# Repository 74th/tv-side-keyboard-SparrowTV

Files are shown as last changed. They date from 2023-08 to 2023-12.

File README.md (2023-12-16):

# TV Side Keyboard SparrowTV

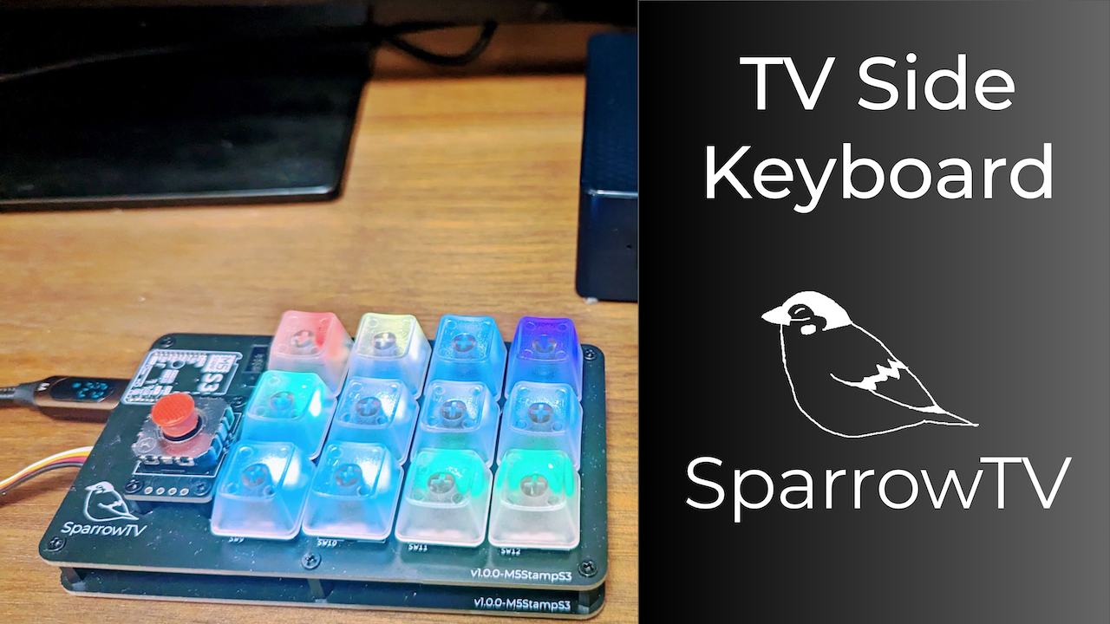
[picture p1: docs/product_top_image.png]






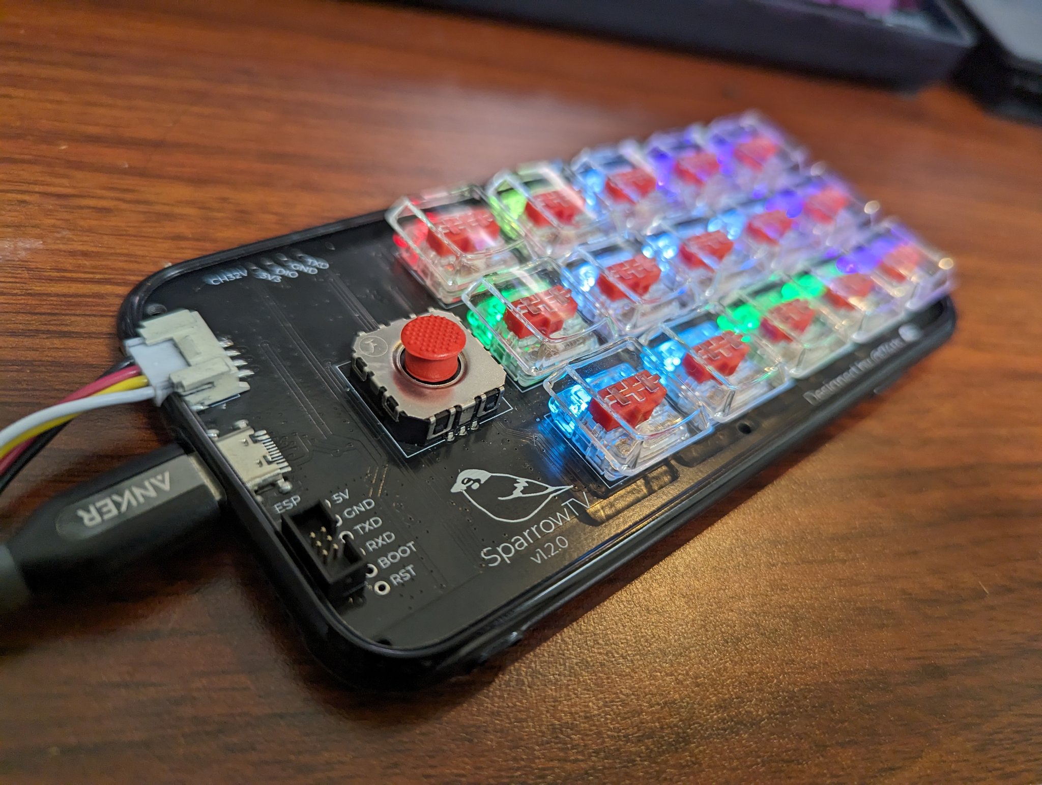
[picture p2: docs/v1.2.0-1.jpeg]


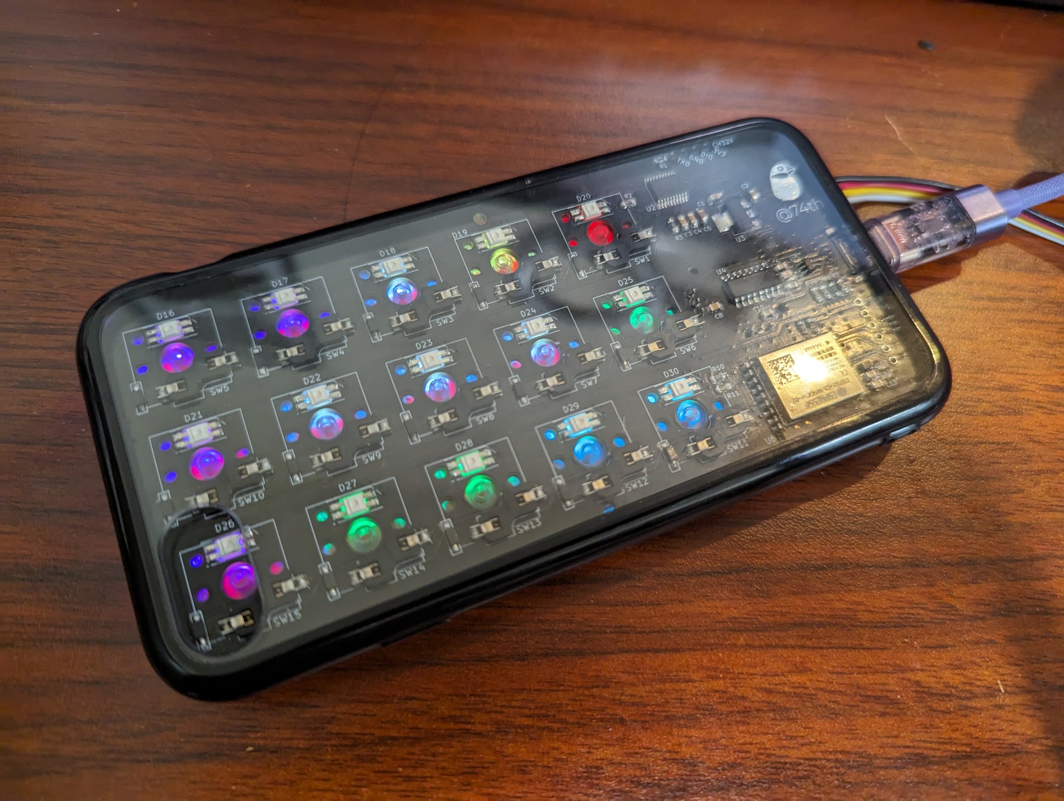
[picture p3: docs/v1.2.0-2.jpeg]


> TV Side Keyboard SparrowTV | ProtoPedia
>
> https://protopedia.net/prototype/4340

> (530) Introduce TV Side Keyboard SparrowTV - YouTube
>
> https://www.youtube.com/watch?v=BaXQt75BodM

この作品は M5Stack Japan Creativity Contest 2023 に応募していました。

ESP32-S3 の USB デバイス機能が使いこなせなかった（USB キーボードでスリープ復帰ができないのを解決できなかった）ので、USB デバイスとして CH9329 を利用し、さらに ESP32-C3 に置き換えました。

## Product versions

### v1.2.0

- ESP32-S3 を ESP32-C3 に置き換え。
- USB キーボードのための IC として CH9329 を利用。
- キーボードマトリックス、ジョイスティックの読み込みに CH32V003F4P6 を利用（v1.0.0 ではジョイスティックのみであった）。

#### Documents

- semantics [pdf](./pcb-kicad/tv-side-keyboard_v1.2.0_semantics.pdf) [kicanvas](https://kicanvas.org/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)
- pcb [kicanvas](https://kicanvas.org/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)

#### BOM

| Reference | Name | Quantity |
| --- | --- | --- |
| C1, C2 | Capacitor 0805 10uF | 2 |
| C3, C4, C6, C8-C10, C12, C13 | Capacitor 0805 100nF | 8 |
| C5, C7, C11 | Capacitor 0805 1uF | 3 |
| CH1 | HY2.0 Socket SMD 4Pin - M5 IR Unit | 1 |
| D1-D15 | Diode SMD 1N4148W | 15 |
| D16-D30 | RGBLED 3528 SK6812MINI-E | 15 |
| J1 | USB Type-C Receptacle | 1 |
| J2 | Box Pin Header 2x3 Pitch 1.27mm | 1 |
| R1 | Register 0805 1Ω | 1 |
| R2 | Register 0805 27Ω | 1 |
| R3, R4, R8, R9 | Register 0805 10kΩ | 4 |
| R5 | Register 0805 42-56kΩ | 1 |
| R6, R7 | Register 0805 5.1kΩ | 2 |
| R10, R11 | Register 0805 1kΩ | 2 |
| SW1-SW15 | Kailh Choc Switch Socket | 15 |
| U1 | Joystick B10K | 1 |
| U2 | MCU TSSOP20 WCH CH32V003F4P6 | 1 |
| U3 | Regulator 3.3V SOT-223 AMS1117-3.3 | 1 |
| U4 | USB Keyboard Mouse Device IC SOIC-16 CH9329 | 1 |
| U5 | USB Power Protection IC SOT-23-6L CH217K | 1 |
| U6 | WiFi MCU Module ESP32-C3-WROOM-02 | 1 |

### v1.0.0

- semantics: [PDF](pcb-kicad/tv-side-keyboard_v1.0.0_semantics.pdf) [kicanvas](https://kicanvas.org/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)
- pcb: [kicanvas](https://kicanvas.org/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)

#### BOM

| Reference | Name | Quantity |
| --- | --- | --- |
| CH1 | HY2.0 Socket SMD 4Pin - JoyPoint | 1 |
| CH2 | HY2.0 Socket SMD 4Pin - M5 IR Unit | 1 |
| D1-D12 | Diode SMD 1N4148W | 12 |
| D13-D24 | RGBLED 3528 SK6812MINI-E | 12 |
| J1 | Box Pin Header 2x3 Pitch 1.27mm | 1 |
| R1 | Capacitor 0805 27F | 1 |
| R2, R3 | Capacitor 0805 10kF | 2 |
| SW1-SW12  | Kailh Choc Switch Socket | 12 |
| U1 | MCU Module M5Stamp S3 | 1 |

## License

MIT

日本では販売しないでいただけると助かります。

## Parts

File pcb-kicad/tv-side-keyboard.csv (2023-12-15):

Reference | Value | Footprint | Sim.Device | Sim.Pins | 数量
C1, C2 | 10u | $74th:Capacitor_0805_2012 |  |  | 2
C3, C4, C6, C8-C10, C12, C13 | 100n | $74th:Capacitor_0805_2012 |  |  | 8
C5, C7, C11 | 1u | $74th:Capacitor_0805_2012 |  |  | 3
CH1 | M5 IR Unit | $74th:HY2.0_Socket_SMD_4Pin |  |  | 1
CH2 | SWD 1Wire & UART TX | 74th:PinOut_4Pin |  |  | 1
D1-D15 | 1N4148W | $sparrow62:D3_SMD_v2 | D | 1=K 2=A | 15
D16-D30 | SK6812MINI | $74th:YS-SK6812MINI-E-BACK-RIGHT |  |  | 15
J1 | Keyboard USB | $74th:USB-C-12-Pin-MidMount-ali-v5 |  |  | 1
J2 | ESPProg-Port | $74th:BoxPinHeader_2x03_P1.27mm_Vertical |  |  | 1
J3 | ESPProg-Port | $74th:6Pin |  |  | 1
R1 | 1 | $74th:Register_0805_2012 |  |  | 1
R2 | 27 | $74th:Register_0805_2012 |  |  | 1
R3, R4, R8, R9 | 10k | $74th:Register_0805_2012 |  |  | 4
R5 | 42k | $74th:Register_0805_2012 |  |  | 1
R6, R7 | 5.1k | $74th:Register_0805_2012 |  |  | 2
R10, R11 | 1k | $74th:Register_0805_2012 |  |  | 2
SW1-SW15 | SW_Push | $sparrow62:Choc_1Side_1.0u |  |  | 15
U1 | joystick-b10k | $74th:JOYSTICK-B10K |  |  | 1
U2 | CH32V003F4P6 | Package_SO:TSSOP-20_4.4x6.5mm_P0.65mm |  |  | 1
U3 | Regulator_AMS117-3.3 | Package_TO_SOT_SMD:SOT-223-3_TabPin2 |  |  | 1
U4 | CH9329 | Package_SO:SOIC-16_3.9x9.9mm_P1.27mm |  |  | 1
U5 | CH217K | Package_TO_SOT_SMD:SOT-23-6 |  |  | 1
U6 | ESP32-C3-WROOM-02 | $74th-imported:ESP32-C3-WROOM-02 |  |  | 1

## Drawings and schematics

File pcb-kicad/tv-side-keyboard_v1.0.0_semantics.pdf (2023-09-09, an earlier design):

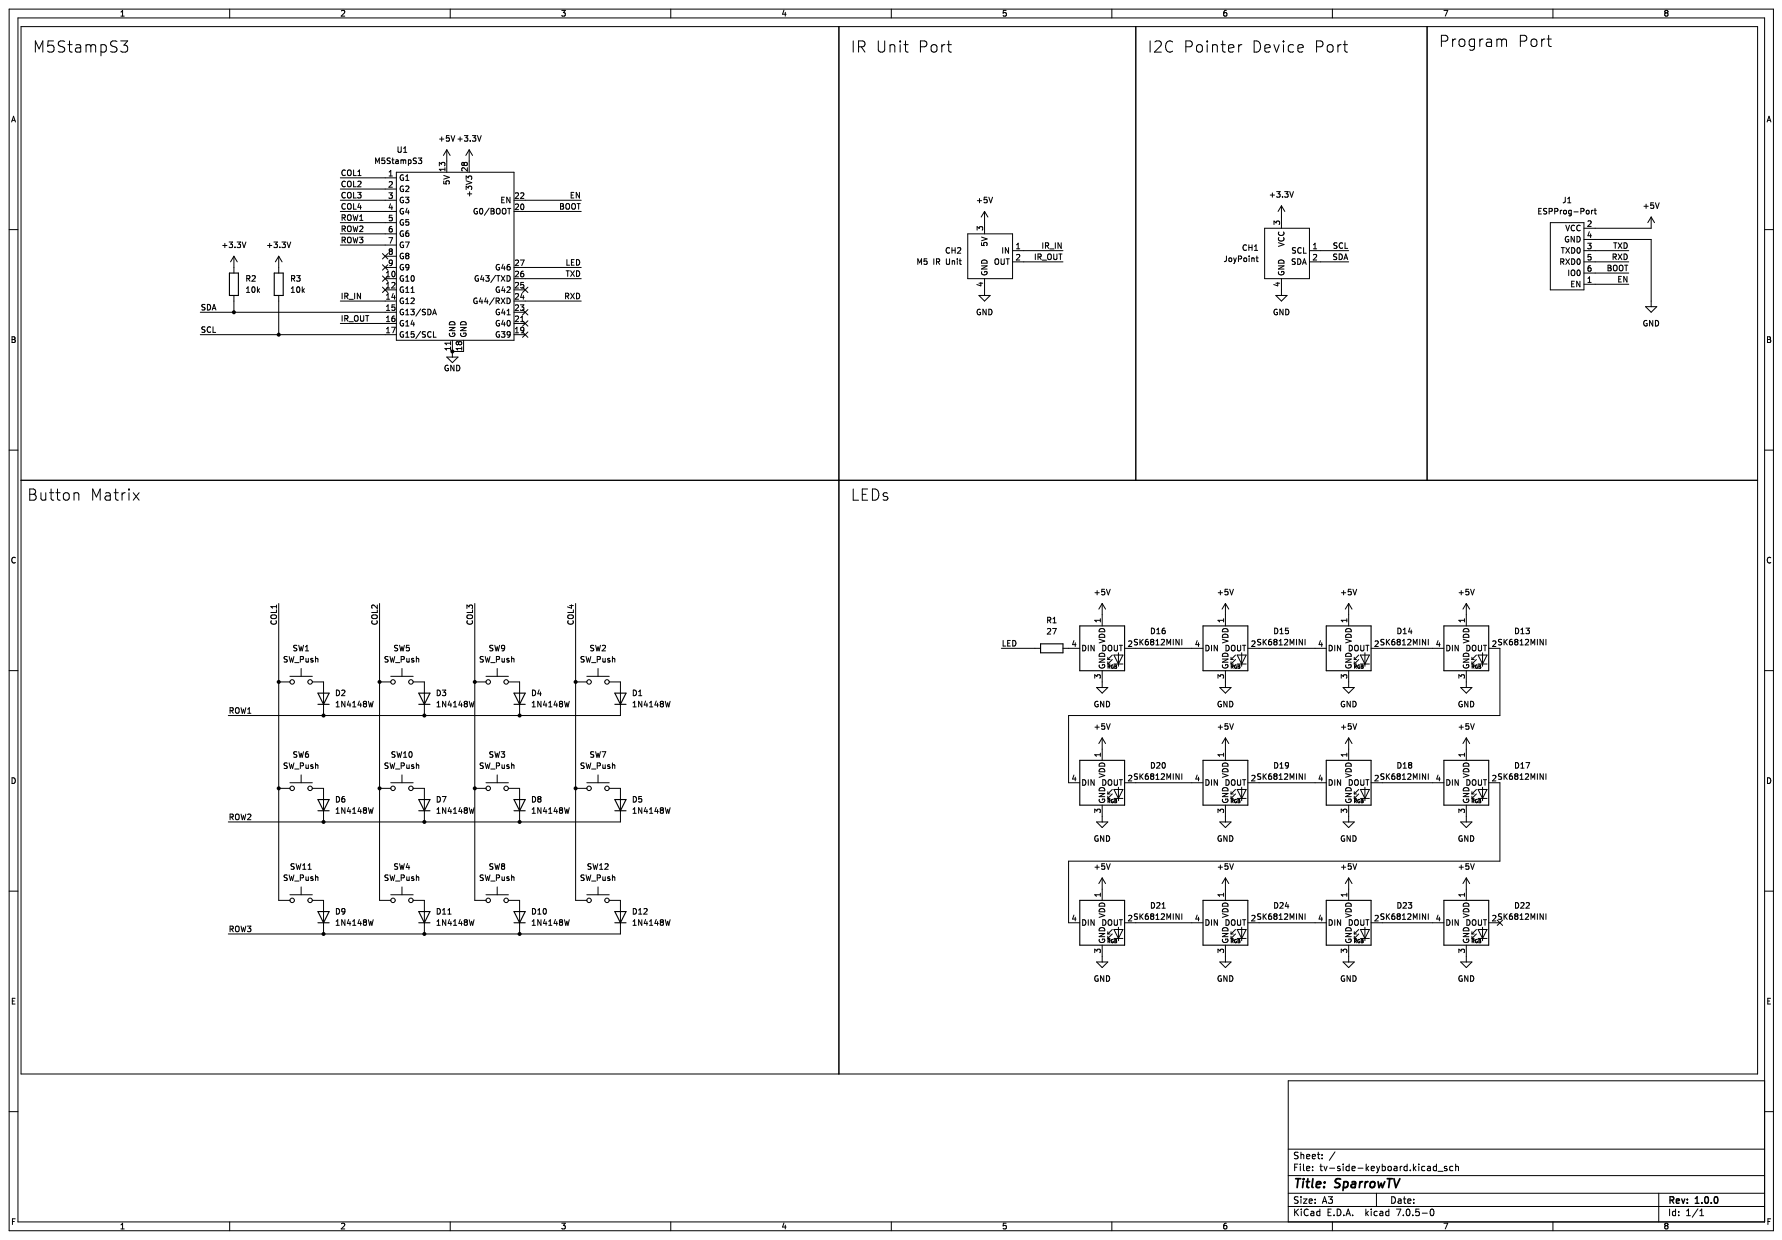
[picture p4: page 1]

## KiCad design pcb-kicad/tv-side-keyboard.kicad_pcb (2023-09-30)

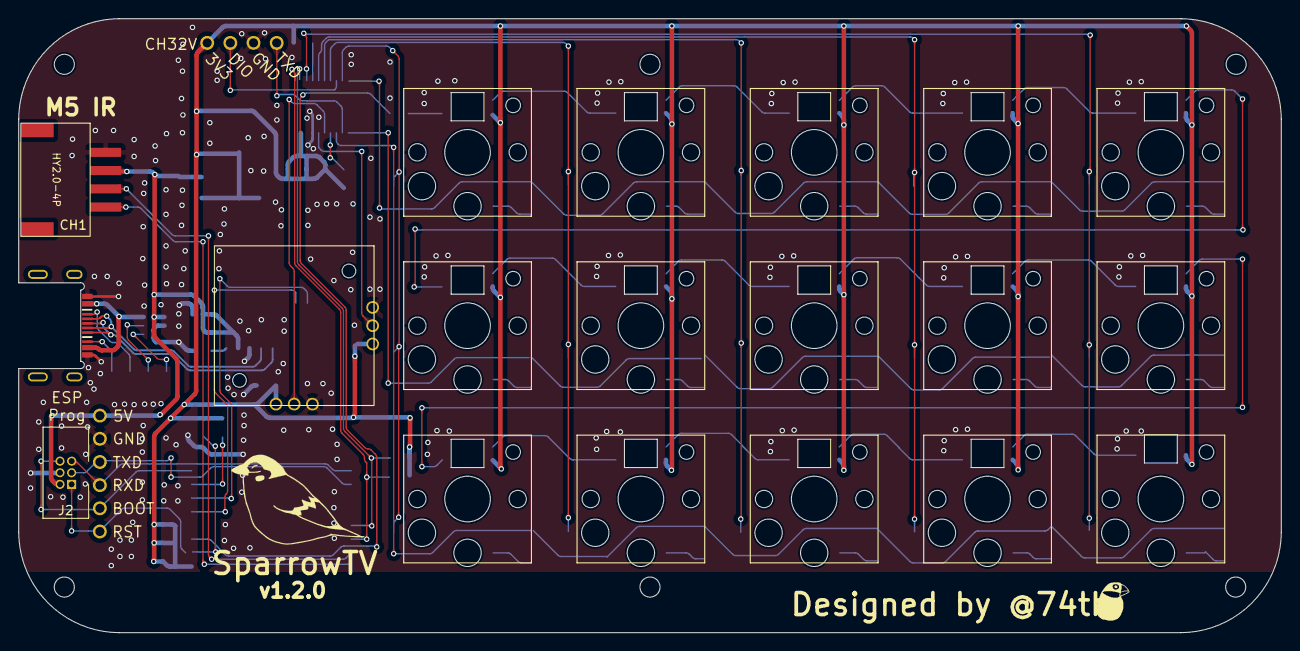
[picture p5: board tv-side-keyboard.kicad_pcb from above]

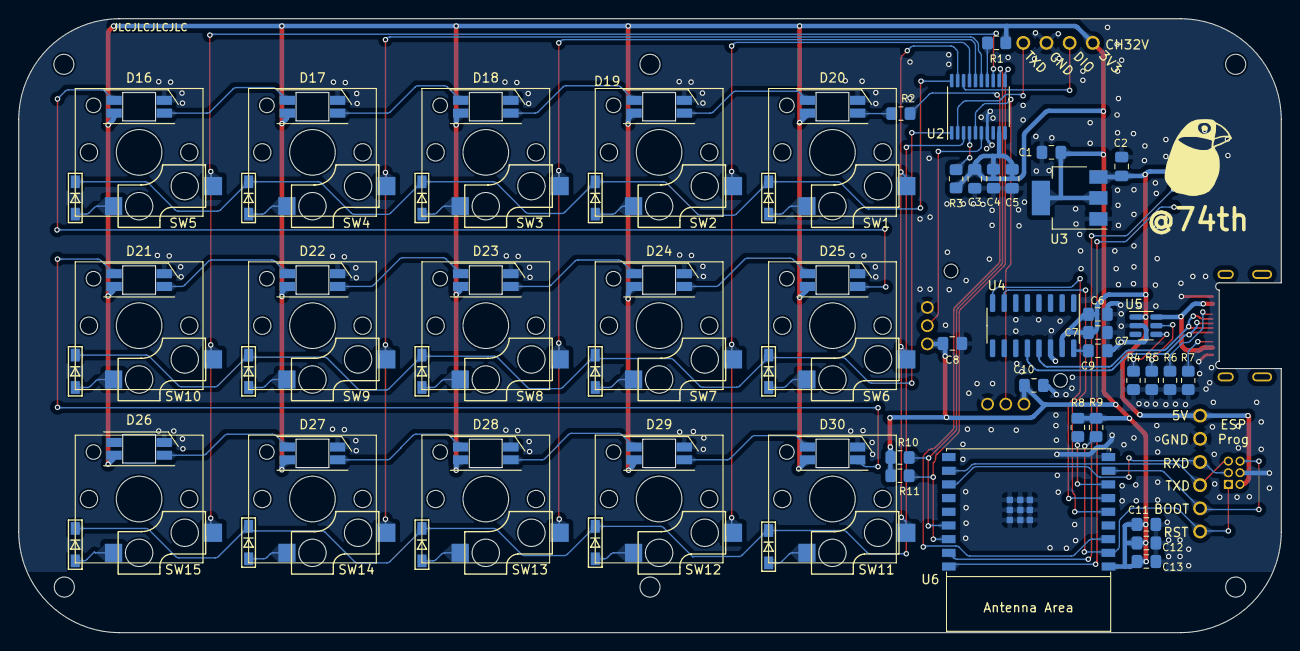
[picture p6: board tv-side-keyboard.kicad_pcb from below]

Board: 2 copper layers, 138.4 x 67.3 mm, 87 parts (46 on the bottom side), 67 nets.

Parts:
C1, C2: 10u; Capacitor_0805_2012
C3, C4, C6, C8, C9, C10, C12, C13: 100n; Capacitor_0805_2012
C5, C7, C11: 1u; Capacitor_0805_2012
CH1: M5 IR Unit; HY2.0_Socket_SMD_4Pin
CH2: SWD 1Wire & UART TX; PinOut_4Pin
D1, D2, D3, D4, D5, D6, D7, D8, D9, D10, D11, D12, D13, D14, D15: 1N4148W; D3_SMD_v2
D16, D17, D18, D19, D20, D21, D22, D23, D24, D25, D26, D27, D28, D29, D30: SK6812MINI; YS-SK6812MINI-E-BACK-RIGHT
J1: Keyboard USB; USB-C-12-Pin-MidMount-ali-v5
J2: ESPProg-Port; BoxPinHeader_2x03_P1.27mm_Vertical
J3: ESPProg-Port; 6Pin
M1, M2, M3, M4, M5, M6: M2-Hole
MISC-ICON: LOGO; Logo_74th_5mm
R1: 1; Register_0805_2012
R2: 27; Register_0805_2012
R3, R4, R8, R9: 10k; Register_0805_2012
R5: 42k; Register_0805_2012
R6, R7: 5.1k; Register_0805_2012
R10, R11: 1k; Register_0805_2012
SW1, SW2, SW3, SW4, SW5, SW6, SW7, SW8, SW9, SW10, SW11, SW12, SW13, SW14, SW15: SW_Push; Choc_1Side_1.0u
U1: joystick-b10k; JOYSTICK-B10K
U2: CH32V003F4P6; TSSOP-20_4.4x6.5mm_P0.65mm
U3: Regulator_AMS117-3.3; SOT-223-3_TabPin2
U4: CH9329; SOIC-16_3.9x9.9mm_P1.27mm
U5: CH217K; SOT-23-6
U6: ESP32-C3-WROOM-02

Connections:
+3.3V: C1.1, C3.1, C4.1, C5.1, C8.1, C10.1, C11.1, C12.1, C13.1, CH2.1 (VCC), D16.1 (VDD), D17.1 (VDD), D18.1 (VDD), D19.1 (VDD), D20.1 (VDD), D21.1 (VDD), D22.1 (VDD), D23.1 (VDD), D24.1 (VDD), D25.1 (VDD), D26.1 (VDD), D27.1 (VDD), D28.1 (VDD), D29.1 (VDD), D30.1 (VDD), R1.1, R3.1, R8.1, R9.1, R10.1, R11.1, U1.1 (XIN1), U1.4 (YIN1), U2.9 (VDD), U3.2 (VO), U6.1 (3V3)
+5V: C2.1, C6.1, C7.1, CH1.3 (5V), J2.2 (VCC), J3.1 (VCC), U3.3 (VI), U4.15 (VCC), U5.1 (VOUT)
/CH32V003_SWDIO: CH2.2 (SWDIO), U2.18 (SWIO/PD1)
/CH32V003_TXD: CH2.4 (TXD), U2.2 (PD5/UART_TX/ADC5)
/CH9329_DM: J1.2 (D-), U4.13 (UD-)
/CH9329_DP: J1.3 (D+), U4.12 (UD+)
/CH9329_RXD: U4.8 (RXD), U6.6 (GPIO7)
/CH9329_TXD: U4.7 (TXD), U6.5 (GPIO6)
/COL1: SW1.1, SW6.1, SW11.1, U2.19 (PD2/ADC3)
/COL2: SW2.1, SW7.1, SW12.1, U2.17 (PC7/SPI_MISO)
/COL3: SW3.1, SW8.1, SW13.1, U2.16 (PC6/SPI_MOSI)
/COL4: SW4.1, SW9.1, SW14.1, U2.15 (PC5/SPI_SCK)
/COL5: SW5.1, SW10.1, SW15.1, U2.13 (PC3)
/ESP32C3_BOOT: J2.6 (IO0), J3.5 (IO0), U6.8 (GPIO9)
/ESP32C3_RST: J2.1 (EN), J3.6 (EN), R9.2, U6.2 (EN/CHIP_PU)
/ESP32C3_RXD: J2.5 (RXD0), J3.4 (RXD0), U6.11 (GPIO20/U0RXD)
/ESP32C3_TXD: J2.3 (TXD0), J3.3 (TXD0), U6.12 (GPIO21/U0TXD)
/IR_IN: CH1.1 (IN), U6.18 (GPIO0/ADC1_CH0/XTAL_32K_P)
/IR_OUT: CH1.2 (OUT), U6.17 (GPIO1/ADC1_CH1/XTAL_32K_N)
/LED: R2.2, U6.3 (GPIO4/ADC1_CH4)
/ROW1: D1.1 (K), D2.1 (K), D3.1 (K), D4.1 (K), D5.1 (K), U2.20 (PD3/UART_CTS/ADC4)
/ROW2: D6.1 (K), D7.1 (K), D8.1 (K), D9.1 (K), D10.1 (K), U2.1 (PD4/UART_CK/ADC7)
/ROW3: D11.1 (K), D12.1 (K), D13.1 (K), D14.1 (K), D15.1 (K), U2.3 (PD6/UART_RX/ADC6)
/SCL: R10.2, U2.12 (PC2/I2C_SCL/UART_RTS), U6.15 (GPIO3/ADC1_CH3)
/SDA: R11.2, U2.11 (PC1/I2C_SDA/SPI_NSS), U6.16 (GPIO2/ADC1_CH2)
/XOUT: U1.2 (XOUT), U2.6 (PA2/ADC0/OSC_OUT)
/YOUT: U1.5 (YOUT), U2.5 (PA1/ADC1/OSC_IN)
GND: C1.2, C2.2, C3.2, C4.2, C5.2, C6.2, C7.2, C8.2, C9.2, C10.2, C11.2, C12.2, C13.2, CH1.4 (GND), CH2.3 (GND), D16.3 (GND), D17.3 (GND), D18.3 (GND), D19.3 (GND), D20.3 (GND), D21.3 (GND), D22.3 (GND), D23.3 (GND), D24.3 (GND), D25.3 (GND), D26.3 (GND), D27.3 (GND), D28.3 (GND), D29.3 (GND), D30.3 (GND), J1.4 (GND), J2.4 (GND), J3.2 (GND), R4.2, R5.2, R6.2, R7.2, U1.3 (XIN2), U1.6 (YIN2), U2.7 (VSS), U3.1 (GND), U4.14 (GND), U5.2 (GND), U6.9 (GND), U6.19 (GND)
unnamed: D1.2 (A), SW1.2
unnamed: D2.2 (A), SW2.2
unnamed: D3.2 (A), SW3.2
unnamed: D4.2 (A), SW4.2
unnamed: D5.2 (A), SW5.2
unnamed: D6.2 (A), SW6.2
unnamed: D7.2 (A), SW7.2
unnamed: D8.2 (A), SW8.2
unnamed: D9.2 (A), SW9.2
unnamed: D10.2 (A), SW10.2
unnamed: D11.2 (A), SW12.2
unnamed: D12.2 (A), SW14.2
unnamed: D13.2 (A), SW13.2
unnamed: D14.2 (A), SW15.2
unnamed: D15.2 (A), SW11.2
unnamed: D16.4 (DIN), D17.2 (DOUT)
unnamed: D16.2 (DOUT), D25.4 (DIN)
unnamed: D17.4 (DIN), D18.2 (DOUT)
unnamed: D18.4 (DIN), D19.2 (DOUT)
unnamed: D19.4 (DIN), D20.2 (DOUT)
unnamed: D20.4 (DIN), R2.1
unnamed: D21.4 (DIN), D22.2 (DOUT)
unnamed: D21.2 (DOUT), D30.4 (DIN)
unnamed: D22.4 (DIN), D23.2 (DOUT)
unnamed: D23.4 (DIN), D24.2 (DOUT)
unnamed: D24.4 (DIN), D25.2 (DOUT)
unnamed: D26.4 (DIN), D27.2 (DOUT)
unnamed: D27.4 (DIN), D28.2 (DOUT)
unnamed: D28.4 (DIN), D29.2 (DOUT)
unnamed: D29.4 (DIN), D30.2 (DOUT)
unnamed: J1.5 (CC1), R6.1
unnamed: J1.6 (CC2), R7.1
unnamed: R1.2, U2.14 (PC4/ADC2)
unnamed: R3.2, U2.4 (PD7/NRST)
unnamed: C9.1, U4.16 (V33)
unnamed: R4.1, U5.4 (EN#)
unnamed: R5.1, U5.5 (ISET)
unnamed: R8.2, U6.7 (GPIO8)
VBUS: J1.1 (VBUS), U5.6 (VIN)

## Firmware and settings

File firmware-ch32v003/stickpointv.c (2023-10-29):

#include "ch32v003fun.h"
#include "stickpointv.h"
#include "ch32v003_GPIO_branchless.h"
#include <stdio.h>

#define I2C_SLAVE_ADDRESS 0xA

#define ADC_NUMCHLS 3
#define I2C_BUF_SIZE 8
#define ROW1_PIN GPIOv_from_PORT_PIN(GPIO_port_D, 3)
#define ROW2_PIN GPIOv_from_PORT_PIN(GPIO_port_D, 4)
#define ROW3_PIN GPIOv_from_PORT_PIN(GPIO_port_D, 6)
#define COL1_PIN GPIOv_from_PORT_PIN(GPIO_port_D, 2)
#define COL2_PIN GPIOv_from_PORT_PIN(GPIO_port_C, 7)
#define COL3_PIN GPIOv_from_PORT_PIN(GPIO_port_C, 6)
#define COL4_PIN GPIOv_from_PORT_PIN(GPIO_port_C, 5)
#define COL5_PIN GPIOv_from_PORT_PIN(GPIO_port_C, 3)

volatile uint8_t i2c_buf[I2C_BUF_SIZE];
volatile uint16_t adc_buf[ADC_NUMCHLS];

void I2C1_EV_IRQHandler(void) __attribute__((interrupt));
void I2C1_ER_IRQHandler(void) __attribute__((interrupt));

void init_rcc(void)
{
    RCC->CFGR0 &= ~(0x1F << 11);

    RCC->APB2PCENR |= RCC_APB2Periph_GPIOA | RCC_APB2Periph_GPIOC | RCC_APB2Periph_GPIOD | RCC_APB2Periph_ADC1;
    RCC->APB1PCENR |= RCC_APB1Periph_I2C1;
}

void init_i2c_slave(uint8_t address)
{
    // https://github.com/cnlohr/ch32v003fun/blob/master/examples/i2c_slave/i2c_slave.h

    // PC1 is SDA, 10MHz Output, alt func, open-drain
    GPIOC->CFGLR &= ~(0xf << (4 * 1));
    GPIOC->CFGLR |= (GPIO_Speed_10MHz | GPIO_CNF_OUT_OD_AF) << (4 * 1);

    // PC2 is SCL, 10MHz Output, alt func, open-drain
    GPIOC->CFGLR &= ~(0xf << (4 * 2));
    GPIOC->CFGLR |= (GPIO_Speed_10MHz | GPIO_CNF_OUT_OD_AF) << (4 * 2);

    // Reset I2C1 to init all regs
    RCC->APB1PRSTR |= RCC_APB1Periph_I2C1;
    RCC->APB1PRSTR &= ~RCC_APB1Periph_I2C1;

    I2C1->CTLR1 |= I2C_CTLR1_SWRST;
    I2C1->CTLR1 &= ~I2C_CTLR1_SWRST;

    // Set module clock frequency
    uint32_t prerate = 2000000; // I2C Logic clock rate, must be higher than the bus clock rate
    I2C1->CTLR2 |= (APB_CLOCK / prerate) & I2C_CTLR2_FREQ;

    // Enable interrupts
    I2C1->CTLR2 |= I2C_CTLR2_ITBUFEN;
    I2C1->CTLR2 |= I2C_CTLR2_ITEVTEN; // Event interrupt
    I2C1->CTLR2 |= I2C_CTLR2_ITERREN; // Error interrupt

    NVIC_EnableIRQ(I2C1_EV_IRQn); // Event interrupt
    NVIC_SetPriority(I2C1_EV_IRQn, 2 << 4);
    NVIC_EnableIRQ(I2C1_ER_IRQn); // Error interrupt
    // Set clock configuration
    uint32_t clockrate = 1000000;                                                    // I2C Bus clock rate, must be lower than the logic clock rate
    I2C1->CKCFGR = ((APB_CLOCK / (3 * clockrate)) & I2C_CKCFGR_CCR) | I2C_CKCFGR_FS; // Fast mode 33% duty cycle
    // I2C1->CKCFGR = ((APB_CLOCK/(25*clockrate))&I2C_CKCFGR_CCR) | I2C_CKCFGR_DUTY | I2C_CKCFGR_FS; // Fast mode 36% duty cycle
    // I2C1->CKCFGR = (APB_CLOCK/(2*clockrate))&I2C_CKCFGR_CCR; // Standard mode good to 100kHz

    // Set I2C address
    I2C1->OADDR1 = address << 1;

    // Enable I2C
    I2C1->CTLR1 |= I2C_CTLR1_PE;

    // Acknowledge the first address match event when it happens
    I2C1->CTLR1 |= I2C_CTLR1_ACK;
}

void init_adc(void)
{
    // https://github.com/cnlohr/ch32v003fun/tree/master/examples/adc_dma_opamp

    // ADCCLK = 24 MHz => RCC_ADCPRE = 0: divide by 2
    RCC->CFGR0 &= ~(0x1F << 11);

    // A0 PA2
    GPIOA->CFGLR &= ~(0xf << (4 * 2)); // CNF = 00: Analog, MODE = 00: Input

    // A1 PA1
    GPIOA->CFGLR &= ~(0xf << (4 * 2)); // CNF = 00: Analog, MODE = 00: Input

    // A2 PA4
    GPIOC->CFGLR &= ~(0xf << (4 * 4)); // CNF = 00: Analog, MODE = 00: Input

    // Reset the ADC to init all regs
    RCC->APB2PRSTR |= RCC_APB2Periph_ADC1;
    RCC->APB2PRSTR &= ~RCC_APB2Periph_ADC1;

    // Set up four conversions on chl 0, 1, 2
    ADC1->RSQR1 = (ADC_NUMCHLS - 1) << 20; // four chls in the sequence
    ADC1->RSQR2 = 0;
    ADC1->RSQR3 = (0 << (5 * 0)) | (1 << (5 * 1)) | (2 << (5 * 2));

    // set sampling time for chl 7, 4, 3, 2
    // 0:7 => 3/9/15/30/43/57/73/241 cycles
    ADC1->SAMPTR2 = (7 << (3 * 0)) | (7 << (3 * 1)) | (7 << (3 * 2));

    // turn on ADC
    ADC1->CTLR2 |= ADC_ADON;

    // Reset calibration
    ADC1->CTLR2 |= ADC_RSTCAL;
    while (ADC1->CTLR2 & ADC_RSTCAL)
        ;

    // Calibrate
    ADC1->CTLR2 |= ADC_CAL;
    while (ADC1->CTLR2 & ADC_CAL)
        ;

    // Turn on DMA
    RCC->AHBPCENR |= RCC_AHBPeriph_DMA1;

    // DMA1_Channel1 is for ADC
    DMA1_Channel1->PADDR = (uint32_t)&ADC1->RDATAR;
    DMA1_Channel1->MADDR = (uint32_t)adc_buf;
    DMA1_Channel1->CNTR = ADC_NUMCHLS;
    DMA1_Channel1->CFGR =
        DMA_M2M_Disable |
        DMA_Priority_VeryHigh |
        DMA_MemoryDataSize_HalfWord |
        DMA_PeripheralDataSize_HalfWord |
        DMA_MemoryInc_Enable |
        DMA_Mode_Circular |
        DMA_DIR_PeripheralSRC;

    // Turn on DMA channel 1
    DMA1_Channel1->CFGR |= DMA_CFGR1_EN;

    // enable scanning
    ADC1->CTLR1 |= ADC_SCAN;

    // Enable continuous conversion and DMA
    ADC1->CTLR2 |= ADC_CONT | ADC_DMA | ADC_EXTSEL;

    // start conversion
    ADC1->CTLR2 |= ADC_SWSTART;
}

void init_gpio(void)
{
    GPIO_port_enable(GPIO_port_C);
    GPIO_port_enable(GPIO_port_D);
    GPIO_pinMode(ROW1_PIN, GPIO_pinMode_I_pullDown, GPIO_Speed_10MHz);
    GPIO_pinMode(ROW2_PIN, GPIO_pinMode_I_pullDown, GPIO_Speed_10MHz);
    GPIO_pinMode(ROW3_PIN, GPIO_pinMode_I_pullDown, GPIO_Speed_10MHz);
    GPIO_pinMode(COL1_PIN, GPIO_pinMode_O_pushPull, GPIO_Speed_10MHz);
    GPIO_pinMode(COL2_PIN, GPIO_pinMode_O_pushPull, GPIO_Speed_10MHz);
    GPIO_pinMode(COL3_PIN, GPIO_pinMode_O_pushPull, GPIO_Speed_10MHz);
    GPIO_pinMode(COL4_PIN, GPIO_pinMode_O_pushPull, GPIO_Speed_10MHz);
    GPIO_pinMode(COL5_PIN, GPIO_pinMode_O_pushPull, GPIO_Speed_10MHz);
}

uint8_t i2c_scan_position = 0;

void I2C1_EV_IRQHandler(void)
{
    uint16_t STAR1, STAR2 __attribute__((unused));
    STAR1 = I2C1->STAR1;
    STAR2 = I2C1->STAR2;

#ifdef FUNCONF_USE_UARTPRINTF
    printf("EV STAR1: 0x%04x STAR2: 0x%04x\r\n", STAR1, STAR2);
#endif

    I2C1->CTLR1 |= I2C_CTLR1_ACK;

    if (STAR1 & I2C_STAR1_ADDR) // 0x0002
    {
#ifdef FUNCONF_USE_UARTPRINTF
        printf("ADDR\r\n");
#endif
        // 最初のイベント
        // read でも write でも必ず最初に呼ばれる
        i2c_scan_position = 0;
    }

    if (STAR1 & I2C_STAR1_RXNE) // 0x0040
    {
#ifdef FUNCONF_USE_UARTPRINTF
        printf("RXNE write event: pos:%d\r\n", i2c_scan_position);
#endif
        // 1byte 受信
        I2C1->DATAR;
    }

    if (STAR1 & I2C_STAR1_TXE) // 0x0080
    {
        // 1byte の read イベント（slave -> master）
#ifdef FUNCONF_USE_UARTPRINTF
        printf("TXE write event: pos:%d\r\n", i2c_scan_position);
#endif
        if (i2c_scan_position < I2C_BUF_SIZE)
        {
            // 1byte 送信
            uint8_t data = i2c_buf[i2c_scan_position];
            I2C1->DATAR = data;
            i2c_scan_position++;
        }
        else
        {
            // 1byte 送信
            I2C1->DATAR = 0x00;
        }
    }
}

void I2C1_ER_IRQHandler(void)
{
    uint16_t STAR1 = I2C1->STAR1;

#ifdef FUNCONF_USE_UARTPRINTF
    printf("ER STAR1: 0x%04x\r\n", STAR1);
#endif

    if (STAR1 & I2C_STAR1_BERR)           // 0x0100
    {                                     // Bus error
        I2C1->STAR1 &= ~(I2C_STAR1_BERR); // Clear error
    }

    if (STAR1 & I2C_STAR1_ARLO)           // 0x0200
    {                                     // Arbitration lost error
        I2C1->STAR1 &= ~(I2C_STAR1_ARLO); // Clear error
    }

    if (STAR1 & I2C_STAR1_AF)           // 0x0400
    {                                   // Acknowledge failure
        I2C1->STAR1 &= ~(I2C_STAR1_AF); // Clear error
    }
}

// const int max = 1024;
const int32_t deadzone = 100;
const int32_t high_zone = 7;
const int32_t middle = 200;
const uint32_t loop_ms = 12;
const uint32_t max_ms = 4028;

int32_t last_center_ms = 0;
int32_t last_high_ms = 0;
int8_t in_dash = 0;

void read_analog(int32_t vcc, int32_t a, int32_t *under, int32_t *upper)
{

    int32_t max = vcc;
    int32_t center = vcc / 2;
    if (a < high_zone)
    {
        *under = 5;
    }
    else if (a < middle)
    {
        *under = 3;
    }
    else if (a < center - deadzone)
    {
        *under = 1;
    }
    else
    {
        *under = 0;
    }

    if (max - high_zone < a)
    {
        *upper = 5;
    }
    else if (max - middle < a)
    {
        *upper = 3;
    }
    else if (center + deadzone < a)
    {
        *upper = 1;
    }
    else
    {
        *upper = 0;
    }
}

void read_stick()
{
    int32_t left = 0;
    int32_t right = 0;
    int32_t up = 0;
    int32_t down = 0;

    int32_t raw_vcc = adc_buf[2];
    int32_t raw_x = adc_buf[1];
    int32_t raw_y = adc_buf[0];
    read_analog(raw_vcc, raw_x, &left, &right);
    read_analog(raw_vcc, raw_y, &down, &up);

    if (left == 0 && right == 0)
    {
        last_center_ms = 0;
    }
    else
    {
        if (last_center_ms < max_ms)
        {
            last_center_ms += loop_ms;
        }
    }

    if (left + right + up + down >= 4)
    {
        if (!in_dash && last_center_ms < 300 && 10 < last_high_ms && last_high_ms < 300)
        {
            in_dash = 1;
        }
        if (in_dash)
        {
            left = left * 2;
            right = right * 2;
            up = up * 2;
            down = down * 2;
        }
        last_high_ms = 0;
    }
    else
    {
        in_dash = 0;
        if (last_high_ms < max_ms)
        {
            last_high_ms += loop_ms;
        }
    }

    i2c_buf[0] = (uint8_t)up;
    i2c_buf[1] = (uint8_t)down;
    i2c_buf[2] = (uint8_t)left;
    i2c_buf[3] = (uint8_t)right;
    i2c_buf[4] = (uint8_t)0;

    // printf("raw_x: %d, raw_y: %d, raw_vcc: %d\r\n", raw_x, raw_y, raw_vcc);
}

void read_switch()
{
    uint8_t row1_buf = 0;
    uint8_t row2_buf = 0;
    uint8_t row3_buf = 0;
    for (int col = 0; col < 5; col++)
    {
        switch (col)
        {
        case 0:
            GPIO_digitalWrite_1(COL1_PIN);
            GPIO_digitalWrite_0(COL2_PIN);
            GPIO_digitalWrite_0(COL3_PIN);
            GPIO_digitalWrite_0(COL4_PIN);
            GPIO_digitalWrite_0(COL5_PIN);
            break;
        case 1:
            GPIO_digitalWrite_0(COL1_PIN);
            GPIO_digitalWrite_1(COL2_PIN);
            GPIO_digitalWrite_0(COL3_PIN);
            GPIO_digitalWrite_0(COL4_PIN);
            GPIO_digitalWrite_0(COL5_PIN);
            break;
        case 2:
            GPIO_digitalWrite_0(COL1_PIN);
            GPIO_digitalWrite_0(COL2_PIN);
            GPIO_digitalWrite_1(COL3_PIN);
            GPIO_digitalWrite_0(COL4_PIN);
            GPIO_digitalWrite_0(COL5_PIN);
            break;
        case 3:
            GPIO_digitalWrite_0(COL1_PIN);
            GPIO_digitalWrite_0(COL2_PIN);
            GPIO_digitalWrite_0(COL3_PIN);
            GPIO_digitalWrite_1(COL4_PIN);
            GPIO_digitalWrite_0(COL5_PIN);
            break;
        case 4:
            GPIO_digitalWrite_0(COL1_PIN);
            GPIO_digitalWrite_0(COL2_PIN);
            GPIO_digitalWrite_0(COL3_PIN);
            GPIO_digitalWrite_0(COL4_PIN);
            GPIO_digitalWrite_1(COL5_PIN);
            break;
        }

        Delay_Us(1);

        row1_buf |= GPIO_digitalRead(ROW1_PIN) << col;
        row2_buf |= GPIO_digitalRead(ROW2_PIN) << col;
        row3_buf |= GPIO_digitalRead(ROW3_PIN) << col;
    }
    i2c_buf[5] = row1_buf;
    i2c_buf[6] = row2_buf;
    i2c_buf[7] = row3_buf;

    // printf("row1: %02X, row1: %02X, row2: %02X\r\n", row1_buf, row2_buf, row3_buf);
}

void raw_adc_test()
{
    uint16_t raw_vcc = adc_buf[2];
    uint16_t raw_x = adc_buf[0];
    uint16_t raw_y = adc_buf[1];
    i2c_buf[0] = (uint8_t)(raw_x >> 2);
    i2c_buf[1] = (uint8_t)(raw_y >> 2);
    i2c_buf[2] = (uint8_t)(raw_vcc >> 2);
    i2c_buf[3] = (uint8_t)0;
    i2c_buf[4] = (uint8_t)0;

    // i2c_buf[0] = (uint8_t)((0xff00 & raw_x) >> 8);
    // i2c_buf[1] = (uint8_t)((0x00ff & raw_x));
    // i2c_buf[2] = (uint8_t)((0xff00 & raw_y) >> 8);
    // i2c_buf[3] = (uint8_t)((0x00ff & raw_y));
}

int main()
{
    SystemInit();
    init_rcc();

    printf("using ch32v003fun\r\n");
    printf("initialize\r\n");

    init_i2c_slave(I2C_SLAVE_ADDRESS);
    init_adc();
    init_gpio();

    printf("initialize done\r\n");

    while (1)
    {
        read_stick();
        read_switch();
        Delay_Ms(loop_ms);
        // raw_adc_test();
        // Delay_Ms(500);
    }
}

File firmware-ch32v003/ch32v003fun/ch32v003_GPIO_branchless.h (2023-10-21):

// 2023-06-26 recallmenot

// ######## necessities

// include guards
#ifndef CH32V003_GPIO_BR_H
#define CH32V003_GPIO_BR_H

// includes
#include <stdint.h> //uintN_t support
#include "ch32v003fun/ch32v003fun.h"

/*######## library description
This is a speedy and light GPIO library due to
    static inlining of most functions
    compile-time abstraction
    branchless where it counts
*/

/*######## library usage and configuration

first, enable the desired port.

digital usage is quite Arduino-like:
pinMode
digitalWrite
digitalWrite_lo
digitalWrite_hi
digitalRead

pins are referenced as a single byte, ST-style:
the upper 4 bytes specify the port, where A is 0, C is 2 etc.
the lower 4 bytes specify the pin
both are used as uint4_t, not as 4 individual bits, allowing to address up to 16 pins on up to 16 ports.
this style of referencing a pin is called "GPIOv" in this library.

additionally, there are functions to operate an entire port at once
this can be useful where setting all pins one by one would be too inefficient / unnecessary
an example where this may be useful: https://www.youtube.com/watch?v=cy6o8TrDUFU
GPIO_port_digitalWrite
GPIO_port_digitalRead



analog-to-digital usage is almost Arduino-like:
pinMode
ADCinit
analogRead

By default, this library inserts a delay of 300 µs between configuration of the ADC input mux and the time the conversion starts.
This serves to counteract the high input impedance of the ADC, especially if it is increased by external resistors.
The input impedance of port A appears to be especially large.
You may modify it to your liking using the following define before including this library.
#define GPIO_ADC_MUX_DELAY 1200

GPIO_ADC_sampletime controls the time each conversion is granted, by default it is GPIO_ADC_sampletime_241cy_default, all options originate from the GPIO_ADC_sampletimes enum.
To alter it, you have 3 options:
 * `#define GPIO_ADC_sampletime GPIO_ADC_sampletime_43cy` before including this library
 * call the GPIO_ADC_set_sampletime function-like macro to momentarrily set it for one channel
 * call the GPIO_ADC_set_sampletimes_all function-like macro to to momentarrily set it for all channels

You may also disable the ADC to save power between infrequent measurements.



digital-to-analog (PWM) usage is quite different:
pinMode
GPIO_timX_map
GPIO_timX_init
GPIO_timX_enableCH
GPIO_timX_analogWrite

This is due to the fact that the CH32V003 has 2 timers, which each can be connected to 4 pre-defined sets (mappings) of pins.
Then you address the 4 channels of the timers, instead of the pins.

By default, the timers will be configured to count up to 2^10, which is 10 bits or 1024 discrete steps.
You may alter this to suit your needs, for example to an 8 bit resolution (256 discrete steps).
Insert this before including this library:
#define GPIO_timer_resolution (1 << 8)

By default, the timers will operate with a clock prescaler of 2 but you may choose 1 or 4 if you wish to alter the speed.
Insert this before including this library:
#define GPIO_timer_prescaler TIM_CKD_DIV1;		// APB_CLOCK / 1024 / 1 = 46.9kHz

You may calculate the base frequency of the timer (the rate of repetition of your signal) like follows:
fpwm = APB_CLOCK / resolution / prescaler
This puts the defaults at an inaudible 23.4kHz.
The higher the frequency, the greater the EMI radiation will be.
With low frequencies, say below 1000Hz, LEDs may exhibit perceivable flicker.

Since this library enables compare capture preload (OCxPE of CHCTLRy), writing a value into the compare register using analogWrite will automatically apply it (=load into shadow register) when the timer starts its next cycle.
This avoids a bug whereby writing a compare value lower than the current counter value, the output will glitch high for the next cycle, resulting in flickery updates.
Writing `TIMx->SWEVGR |= TIM_UG` will immediately update the shadow register and cause the same issue.

*/

// ######## ports, pins and states: use these for the functions below!

#define GPIOv_from_PORT_PIN(GPIO_port_n, pin)

enum GPIO_port_n
{
    GPIO_port_A = 0b00,
    GPIO_port_C = 0b10,
    GPIO_port_D = 0b11,
};

enum GPIO_pinModes
{
    GPIO_pinMode_I_floating,
    GPIO_pinMode_I_pullUp,
    GPIO_pinMode_I_pullDown,
    GPIO_pinMode_I_analog,
    GPIO_pinMode_O_pushPull,
    GPIO_pinMode_O_openDrain,
    GPIO_pinMode_O_pushPullMux,
    GPIO_pinMode_O_openDrainMux,
};

enum lowhigh
{
    low,
    high,
};

// analog inputs
enum GPIO_analog_inputs
{
    GPIO_Ain0_A2,
    GPIO_Ain1_A1,
    GPIO_Ain2_C4,
    GPIO_Ain3_D2,
    GPIO_Ain4_D3,
    GPIO_Ain5_D5,
    GPIO_Ain6_D6,
    GPIO_Ain7_D4,
    GPIO_AinVref,
    GPIO_AinVcal,
};
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

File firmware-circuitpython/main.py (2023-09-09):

import master
import uart_logging_handler
import adafruit_logging as logging

logger = logging.getLogger()


def main():
    uart_logging_handler.setup()
    logger.info("start initialize")
    m = master.Master()
    m.setup()
    logger.info("done")
    logger.info("start running")
    m.run()


if __name__ == "__main__":
    main()

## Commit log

2023-07-30 add matrix buttons
2023-07-30 matrix led
2023-08-28 update kicad
    [tv-side-keyboard.kicad_pcb, tv-side-keyboard.kicad_sch]
2023-08-29 update BOM
    [tv-side-keyboard.csv, tv-side-keyboard.kicad_pcb, tv-side-keyboard.kicad_sch]
2023-09-30 iphone se 2 sized
    [tv-side-keyboard.kicad_pcb, tv-side-keyboard.kicad_sch]
2025-01-26 update wheel, key sequence
